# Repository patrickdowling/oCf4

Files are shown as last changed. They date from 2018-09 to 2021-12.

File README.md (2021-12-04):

# OC + F4
For grins I made an F405-based Teensy replacement for [o\_C](https://github.com/patrickdowling/O_C).

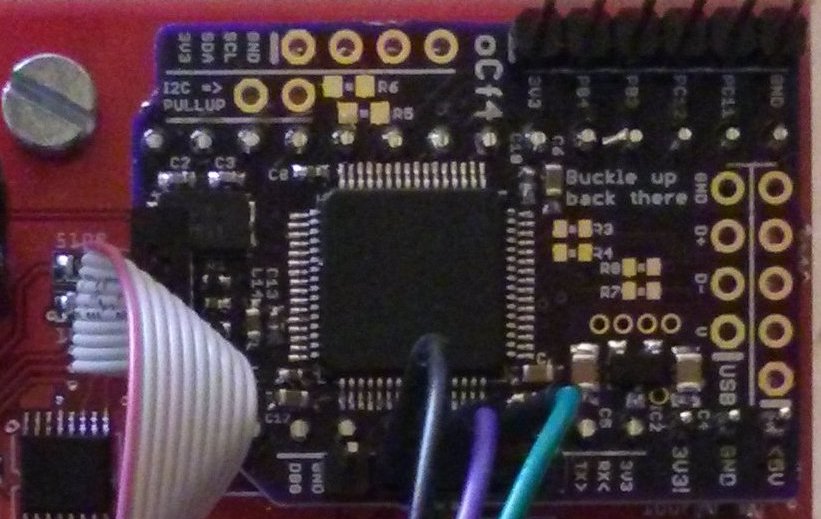
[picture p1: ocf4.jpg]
OCF4


It seemed like a good idea at the time and was an "excuse" to add F4 support to my F0 framework which then became
[stm32x](https://github.com/patrickdowling/stm32x).

The four-layer board is pretty tightly packed and tried to include everything and the kitchen sink (I2C, serial/MIDI, USB header...). There's even space for an SPI flash chip on the bottom... It should also be noted that I'm really just winging it when it comes to hardware design.

The single point of annoyance (the shared SPI between the DAC and screen) however remains although it is possible to run the thing at closer to 30KHz here (the Teensy 3.2 on `o_C` was effectively maxxing out at 16.6KHz with the 30MHz SPI).

Utlimately though, once the base drivers (ADC/TR/DAC/screen) were working it didn't actually have a purpose so there's very little actual functionality. Except a very early draft of what might be a "better" framework. So here it is anyway, warts
and all.

If someone does want to pursue this further, let me know.

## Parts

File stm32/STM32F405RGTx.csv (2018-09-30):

Position | Name | Type | Signal | Label
1 | VBAT | Power
2 | PC13-ANTI_TAMP | Output | GPIO_Output | RST_DAC
3 | PC14-OSC32_IN | Output | GPIO_Output | CS_DAC
4 | PC15-OSC32_OUT | I/O
5 | PH0-OSC_IN | I/O | RCC_OSC_IN
6 | PH1-OSC_OUT | I/O | RCC_OSC_OUT
7 | NRST | Reset
8 | PC0 | Output | GPIO_Output | FLASH_CS
9 | PC1 | I/O
10 | PC2 | I/O
11 | PC3 | I/O
12 | VSSA | Power
13 | VDDA | Power
14 | PA0-WKUP | Input | GPIO_Input | ENC_R2
15 | PA1 | Input | GPIO_Input | ENC_R1
16 | PA2 | Input | GPIO_Input | SW_R
17 | PA3 | Input | GPIO_Input | GND
18 | VSS | Power
19 | VDD | Power
20 | PA4 | Output | GPIO_Output | DBG
21 | PA5 | I/O | SPI1_SCK
22 | PA6 | Input | GPIO_Input | ENC_L2
23 | PA7 | I/O | ADC1_IN7 | CV2
24 | PC4 | I/O | ADC1_IN14 | CV4
25 | PC5 | I/O | ADC1_IN15 | CV3
26 | PB0 | I/O | ADC1_IN8 | CV1
27 | PB1 | Input | GPIO_Input | USB_PWR_FAULT
28 | PB2 | Input | GPIO_Input | ENC_L1
29 | PB10 | I/O | USART3_TX
30 | PB11 | I/O | USART3_RX
31 | VCAP_1 | Power
32 | VDD | Power
33 | PB12 | Input | GPIO_Input | SW_L
34 | PB13 | I/O | SPI2_SCK
35 | PB14 | I/O | SPI2_MISO
36 | PB15 | I/O | SPI2_MOSI
37 | PC6 | I/O | TIM3_CH1 | TR2
38 | PC7 | I/O | TIM3_CH2 | TR1
39 | PC8 | I/O | TIM3_CH3 | TR3
40 | PC9 | I/O | TIM3_CH4 | TR4
41 | PA8 | Output | GPIO_Output | USB_PWR_EN
42 | PA9 | Input | GPIO_Input | USB_OTG_FS_VBUS
43 | PA10 | I/O | USB_OTG_FS_ID
44 | PA11 | I/O | USB_OTG_FS_DM
45 | PA12 | I/O | USB_OTG_FS_DP
46 | PA13 | I/O | SYS_JTMS-SWDIO
47 | VCAP_2 | Power
48 | VDD | Power
49 | PA14 | I/O | SYS_JTCK-SWCLK
50 | PA15 | Input | GPIO_Input | SW_T
51 | PC10 | Input | GPIO_Input | SW_B
52 | PC11 | Output | GPIO_Output | PC11
53 | PC12 | Output | GPIO_Output | PC12
54 | PD2 | Output | GPIO_Output | DC
55 | PB3 | Output | GPIO_Output | PB3
56 | PB4 | Output | GPIO_Output | PB4
57 | PB5 | I/O | SPI1_MOSI
58 | PB6 | Output | GPIO_Output | RST
59 | PB7 | Output | GPIO_Output | CS_OLED
60 | BOOT0 | Boot
61 | PB8 | I/O | I2C1_SCL
62 | PB9 | I/O | I2C1_SDA
63 | VSS | Power
64 | VDD | Power

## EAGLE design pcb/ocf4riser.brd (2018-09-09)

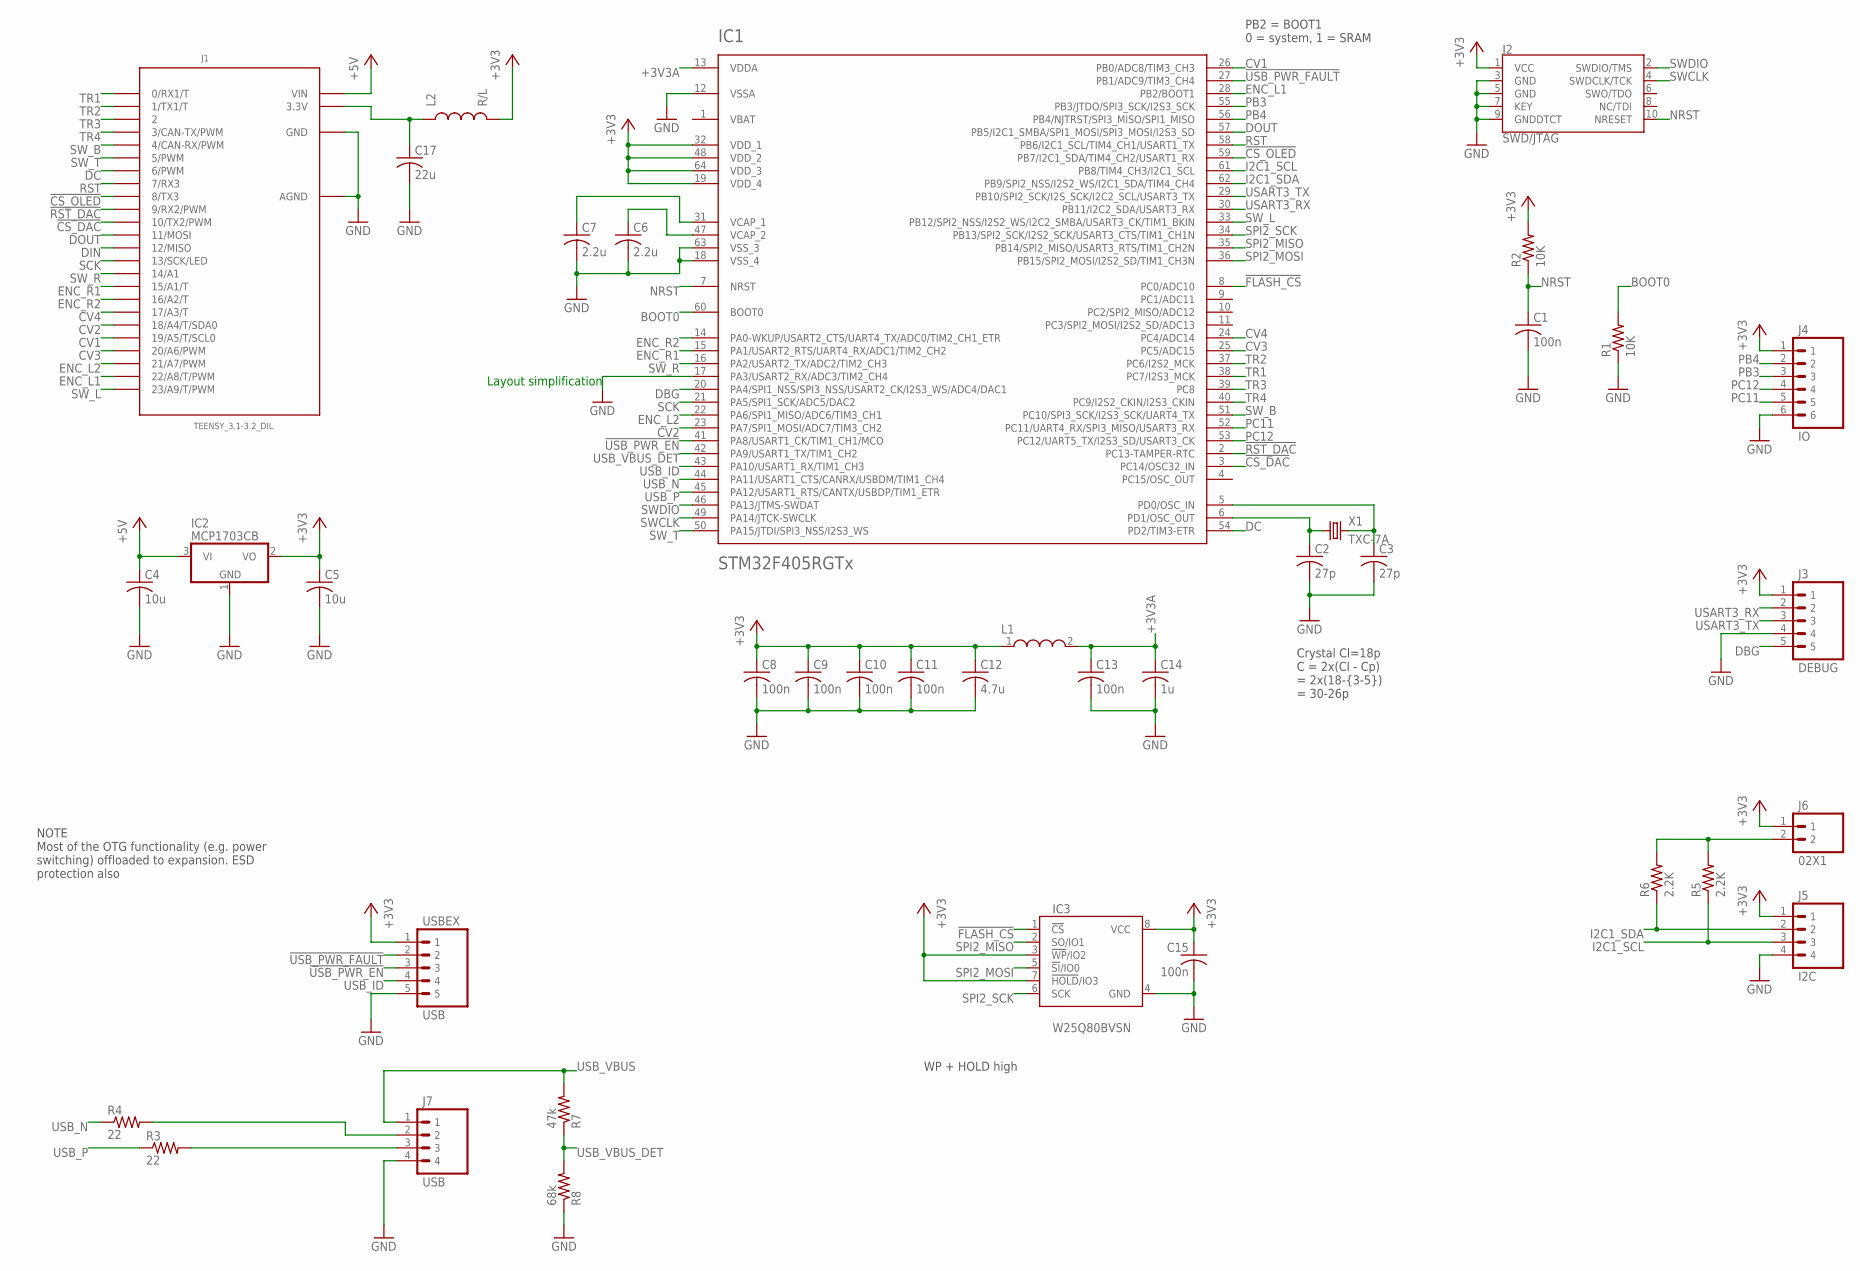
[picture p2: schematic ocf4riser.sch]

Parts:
C1, C8, C9, C10, C11, C13, C15: 100n; C0402
C2, C3: 27p; C0402
C4, C5: 10u; C0805
C6, C7: 2.2u; C0603
C12: 4.7u; C0603
C14: 1u; C0603
C17: 22u; C0805
IC1: STM32F405RGTx; TQFP-10X10-64
IC2: MCP1703CB; SOT23
IC3: W25Q80BVSN; SOIC-8
J1: TEENSY_3.1-3.2_DIL; TEENSY_3.0-3.2&LC_DIL
J2: SWD/JTAG; 2X5-1.27
J3: DEBUG; 05X1-THIN
J4: IO; 06X1-THIN
J5: I2C; 04X1-THIN
J6: 02X1; 02X1-THIN
J7: USB; 04X1-THIN
L1: WE-CBF_0603(WB/HS); WE-CBF_0603(W=2.2)
L2: R/L; 0805
R1, R2: 10K; R0402
R3, R4: 22; R0402
R5, R6: 2.2K; R0603
R7: 47k; R0402
R8: 68k; R0402
USBEX: USB; 05X1-THIN
X1: TXC-7A; CRYSTAL-TXC-7A

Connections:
!CS_DAC: IC1.3 (PC14/OSC32_IN), J1.10 (10/TX2/PWM)
!CS_OLED: IC1.59 (PB7/I2C1_SDA/TIM4_CH2/USART1_RX), J1.8 (8/TX3)
!FLASH_CS: IC1.8 (PC0/ADC10), IC3.1 (!CS!)
!RST_DAC: IC1.2 (PC13-TAMPER-RTC), J1.9 (9/RX2/PWM)
!USB_PWR_EN: IC1.41 (PA8/USART1_CK/TIM1_CH1/MCO), USBEX.3
!USB_PWR_FAULT: IC1.27 (PB1/ADC9/TIM3_CH4), USBEX.2
+3V3: C5.1, C8.1, C9.1, C10.1, C11.1, C12.1, C15.1, IC1.19 (VDD_4), IC1.32 (VDD_1), IC1.48 (VDD_2), IC1.64 (VDD_3), IC2.2 (VO), IC3.3 (!WP!/IO2), IC3.7 (!HOLD!/IO3), IC3.8 (VCC), J2.1 (VCC), J3.1, J4.1, J5.1, J6.1, L1.1, L2.2, R2.2, USBEX.1
+3V3A: C13.1, C14.1, IC1.13 (VDDA), L1.2
+5V: C4.1, IC2.3 (VI), J1.VIN
BOOT0: IC1.60 (BOOT0), R1.2
CV1: IC1.26 (PB0/ADC8/TIM3_CH3), J1.19/A5 (19/A5/T/SCL0)
CV2: IC1.23 (PA7/SPI1_MOSI/ADC7/TIM3_CH2), J1.18/A4 (18/A4/T/SDA0)
CV3: IC1.25 (PC5/ADC15), J1.20/A6 (20/A6/PWM)
CV4: IC1.24 (PC4/ADC14), J1.17/A3 (17/A3/T)
DBG: IC1.20 (PA4/SPI1_NSS/SPI3_NSS/USART2_CK/I2S3_WS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), J3.5
DC: IC1.54 (PD2/TIM3-ETR), J1.6 (6/PWM)
DIN: J1.12 (12/MISO)
DOUT: IC1.57 (PB5/I2C1_SMBA/SPI1_MOSI/SPI3_MOSI/I2S3_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), J1.11 (11/MOSI)
ENC_L1: IC1.28 (PB2/BOOT1), J1.22/A8 (22/A8/T/PWM)
ENC_L2: IC1.22 (PA6/SPI1_MISO/ADC6/TIM3_CH1), J1.21/A7 (21/A7/PWM)
ENC_R1: IC1.15 (PA1/USART2_RTS/UART4_RX/ADC1/TIM2_CH2), J1.15/A1 (15/A1/T)
ENC_R2: IC1.14 (PA0-WKUP/USART2_CTS/UART4_TX/ADC0/TIM2_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), J1.16/A2 (16/A2/T)
GND: C1.2, C2.2, C3.2, C4.2, C5.2, C6.2, C7.2, C8.2, C9.2, C10.2, C11.2, C12.2, C13.2, C14.2, C15.2, C17.2, IC1.12 (VSSA), IC1.17 (PA3/USART2_RX/ADC3/TIM2_CH4), IC1.18 (VSS_4), IC1.63 (VSS_3), IC2.1 (GND), IC3.4 (GND), J1.AGND, J1.GND, J2.3 (GND), J2.5 (GND), J2.7 (KEY), J2.9 (GNDDTCT), J3.4, J4.6, J5.4, J7.4, R1.1, R8.1, USBEX.5
I2C1_SCL: IC1.61 (PB8/TIM4_CH3/I2C1_SCL), J5.3, R5.1
I2C1_SDA: IC1.62 (PB9/SPI2_NSS/I2S2_WS/I2C1_SDA/TIM4_CH4), J5.2, R6.1
I2C_PU: J6.2, R5.2, R6.2
unnamed: C17.1, J1.3.3V, L2.1
unnamed: C3.1, IC1.5 (PD0/OSC_IN), X1.P$2 (2)
unnamed: C2.1, IC1.6 (PD1/OSC_OUT), X1.P$1 (1)
NRST: C1.1, IC1.7 (NRST), J2.10 (NRESET), R2.1
PB3: IC1.55 (PB3/JTDO/SPI3_SCK/I2S3_SCK), J4.3
PB4: IC1.56 (PB4/NJTRST/SPI3_MISO/SPI1_MISO), J4.2
PC11: IC1.52 (PC11/UART4_RX/SPI3_MISO/USART3_RX), J4.5
PC12: IC1.53 (PC12/UART5_TX/I2S3_SD/USART3_CK), J4.4
RST: IC1.58 (PB6/I2C1_SCL/TIM4_CH1/USART1_TX), J1.7 (7/RX3)
SCK: IC1.21 (PA5/SPI1_SCK/ADC5/DAC2), J1.13 (13/SCK/LED)
SPI2_MISO: IC1.35 (PB14/SPI2_MISO/USART3_RTS/TIM1_CH2N), IC3.2 (SO/IO1)
SPI2_MOSI: IC1.36 (PB15/SPI2_MOSI/I2S2_SD/TIM1_CH3N), IC3.5 (!SI!/IO0)
SPI2_SCK: IC1.34 (PB13/SPI2_SCK/I2S2_SCK/USART3_CTS/TIM1_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), IC3.6 (SCK)
SWCLK: IC1.49 (PA14/JTCK-SWCLK), J2.4 (SWDCLK/TCK)
SWDIO: IC1.46 (PA13/JTMS-SWDAT), J2.2 (SWDIO/TMS)
SW_B: IC1.51 (PC10/SPI3_SCK/I2S3_SCK/UART4_TX), J1.4 (4/CAN-RX/PWM)
SW_L: IC1.33 (PB12/SPI2_NSS/I2S2_WS/I2C2_SMBA/USART3_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), J1.23/A9 (23/A9/T/PWM)
SW_R: IC1.16 (PA2/USART2_TX/ADC2/TIM2_CH3), J1.14/A0 (14/A1)
SW_T: IC1.50 (PA15/JTDI/SPI3_NSS/I2S3_WS), J1.5 (5/PWM)
TR1: IC1.38 (PC7/I2S3_MCK), J1.0 (0/RX1/T)
TR2: IC1.37 (PC6/I2S2_MCK), J1.1 (1/TX1/T)
TR3: IC1.39 (PC8), J1.2
TR4: IC1.40 (PC9/I2S2_CKIN/I2S3_CKIN), J1.3 (3/CAN-TX/PWM)
USART3_RX: IC1.30 (PB11/I2C2_SDA/USART3_RX), J3.2
USART3_TX: IC1.29 (PB10/SPI2_SCK/I2S_SCK/I2C2_SCL/USART3_TX), J3.3
USB_ID: IC1.43 (PA10/USART1_RX/TIM1_CH3), USBEX.4
USB_I_N: J7.2, R4.2
USB_I_P: J7.3, R3.2
USB_N: IC1.44 (PA11/USART1_CTS/CANRX/USBDM/TIM1_CH4), R4.1
USB_P: IC1.45 (PA12/USART1_RTS/CANTX/USBDP/TIM1_ETR), R3.1
USB_VBUS: J7.1, R7.2
USB_VBUS_DET: IC1.42 (PA9/USART1_TX/TIM1_CH2), R7.1, R8.2
VBAT: IC1.1 (VBAT)
VCAP_1: C7.1, IC1.31 (VCAP_1)
VCAP_2: C6.1, IC1.47 (VCAP_2)

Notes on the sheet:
Layout simplification
PB2 = BOOT1 0 = system, 1 = SRAM
WP + HOLD high
NOTE Most of the OTG functionality (e.g. power switching) offloaded to expansion. ESD protection also
Crystal Cl=18p C = 2x(Cl - Cp) = 2x(18-{3-5}) = 30-26p

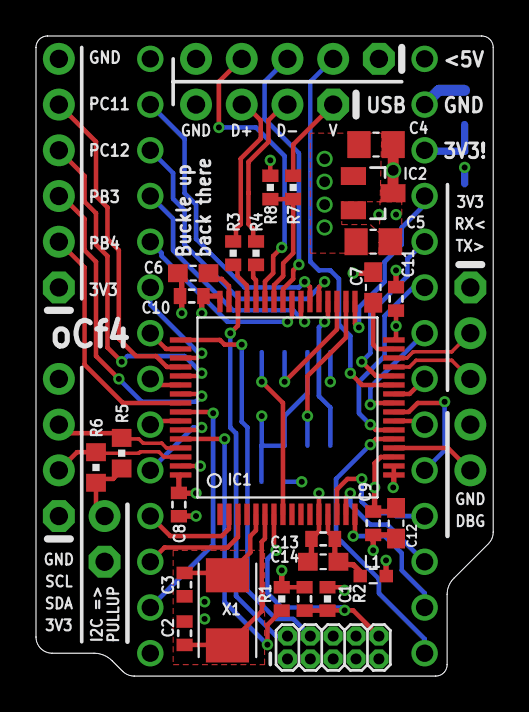
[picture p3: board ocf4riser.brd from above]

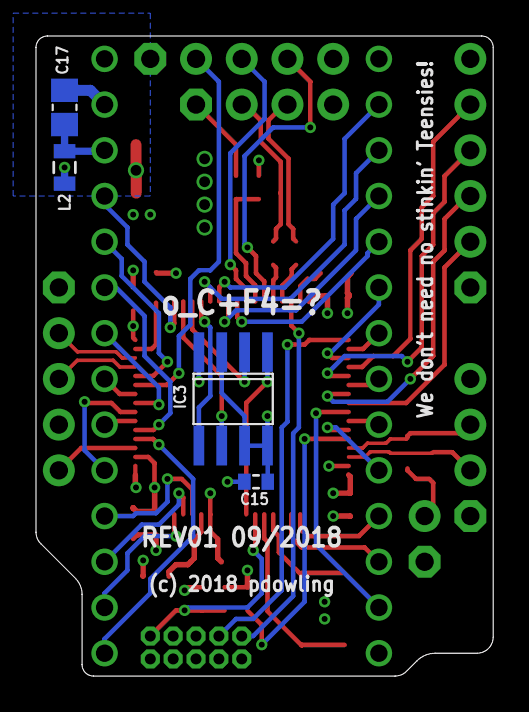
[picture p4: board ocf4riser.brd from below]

Board: 4 copper layers, 25.4 x 35.6 mm, 38 parts (4 on the bottom side), 59 nets.

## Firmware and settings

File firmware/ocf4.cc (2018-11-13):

// Copyright 2018 Patrick Dowling
//
// Author: Patrick Dowling (pld@gurkenkiste.com)
//
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
// See http://creativecommons.org/licenses/MIT/ for more information.
//
// Main runtime for ocf4

#include "ocf4.h"
#include "calibration_data.h"
#include "display.h"
#include "patch.h"
#include "drivers/adc.h"
#include "drivers/digital_inputs.h"
#include "drivers/gpio.h"
#include "drivers/core_timer.h"
#include "drivers/dac.h"
#include "drivers/serial_port.h"
#include "stm32x/stm32x_core.h"
#include "stm32x/stm32x_debug.h"
#include "ui/ui.h"
#include "builtin/calibration_patch.h"
#include "builtin/debug_menu.h"
#include "builtin/io_frame_debug.h"

namespace ocf4 {

  DebugStats DEBUG_STATS;
  CalibrationData calibration_data;

  GPIO gpio;
  Adc adc;
  CoreTimer core_timer;
  DigitalInputs digital_inputs;
  Spi shared_spi;
  Display display{shared_spi};
  Dac dac{shared_spi};
  SerialPort serial_port;

  Ui ui;
  DebugMenu debug_menu;

} // namespace ocf4
STM32X_CORE_DEFINE()

using namespace ocf4;
using namespace stm32x;

static PatchMemoryPool patch_memory_pool;
static Patch current_patch{patch_memory_pool};
static IOFrame io_frame;
static IOFrameDebug io_frame_debug{io_frame};

extern "C" void CORE_TIMER_HANDLER() {
  if (!core_timer.Ticked())
    return;

  DEBUG_PROFILE_SCOPE(DEBUG_STATS.CORE.core_timer_cycles);
  display.Flush();
  dac.Update(io_frame.out);
  adc.Read(io_frame.adc_in);
  adc.StartConversion();
  digital_inputs.Read(io_frame.digital_inputs);
  display.Update();
  ++io_frame.tick;

  // Stuff happens here
  if (current_patch.enabled())
    current_patch.Process(io_frame);
}

extern "C" void SysTick_Handler() {
  STM32X_CORE_TICK();
  ui.Poll();
  ui.Tick();
}

class TestProc : public Processor {
public:
  static constexpr uint32_t type_id = FOURCC<'T','E','S','T'>::value;
  virtual void Init(PatchMemoryPool &) final { }
  virtual void Process(IOFrame &frame) final {
    frame.out[0] = a++;
    frame.out[1] = b++;
  }

private:
  uint16_t a = 0, b = 0xffff/4, c = 0xffff/2, d = 0xffff*3 / 4;
};

class TestProcGate : public Processor {
public:
  static constexpr uint32_t type_id = FOURCC<'G','A','T','E'>::value;

  TestProcGate(uint32_t pw) {
    pw_.set(pw);
  }

  virtual void Init(PatchMemoryPool &) final { }
  virtual void Process(IOFrame &frame) final {
    if (ticks_ > pw_.value()) {
      frame.out[2] = 65535;
      frame.out[3] = 0;
    } else {
      frame.out[2] = 0;
      frame.out[3] = 65535;
    }
    ++ticks_;
    if (ticks_ > kCoreUpdate)
      ticks_ = 0;
  }

  ParameterList parameter_list() const {
    return ParameterList(parameters_.size(), parameters_.data());
  }

private:
  uint32_t ticks_ = 0;
  EditableParameter<uint32_t> pw_ = {"PW", kCoreUpdate / 2};

  const std::array<EditableParameterBase*, 2> parameters_ = {
    &pw_,
    nullptr
  };
};

int main()
{
  STM32X_DEBUG_INIT();
  STM32X_CORE_INIT(F_CPU / kSysTickUpdate);

  // FIXME Init order smells suspicious

  debug_menu.Init();
  debug_menu.AddPage("IO", &io_frame_debug);
  debug_menu.AddPage("PATCH", &current_patch);
  ui.PushMenu(&debug_menu);

  display.AdjustOffset(calibration_data.display_offset);
  display.Init();
/*
  CalibrationPatch::Load(current_patch);
  ui.PushMenu(current_patch.root_menu());
*/

  current_patch.Reset();
  current_patch.AddProcessor<TestProc>();
  current_patch.AddProcessor<TestProcGate>(kCoreUpdate / 2);
  current_patch.enable(true);

  serial_port.Init(9600);

  core_timer.Start(F_CPU / kCoreUpdate - 1);
  while (true) {
    ui.DispatchEvents();
    current_patch.IdleLoop();
    ui.Draw();

    while (serial_port.readable()) {
      switch (serial_port.Read()) {
        case '?': serial_port.Write('!');
        default: break;
      }
    }
 }
}

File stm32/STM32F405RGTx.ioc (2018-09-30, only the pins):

Mcu.UserName=STM32F405RGTx
PA0-WKUP.GPIO_Label=ENC_R2
PA0-WKUP.Signal=GPIO_Input
PA1.GPIO_Label=ENC_R1
PA1.Signal=GPIO_Input
PA10.Signal=USB_OTG_FS_ID
PA11.Signal=USB_OTG_FS_DM
PA12.Signal=USB_OTG_FS_DP
PA13.Signal=SYS_JTMS-SWDIO
PA14.Signal=SYS_JTCK-SWCLK
PA15.GPIO_Label=SW_T
PA15.Signal=GPIO_Input
PA2.GPIO_Label=SW_R
PA2.Signal=GPIO_Input
PA3.GPIO_Label=GND
PA3.Signal=GPIO_Input
PA4.GPIO_Label=DBG
PA4.Signal=GPIO_Output
PA5.Signal=SPI1_SCK
PA6.GPIO_Label=ENC_L2
PA6.Signal=GPIO_Input
PA7.GPIO_Label=CV2
PA7.Signal=ADCx_IN7
PA8.GPIO_Label=USB_PWR_EN
PA8.Signal=GPIO_Output
PA9.GPIO_Label=USB_OTG_FS_VBUS
PA9.Signal=GPIO_Input
PB0.GPIO_Label=CV1
PB0.Signal=ADCx_IN8
PB1.GPIO_Label=USB_PWR_FAULT
PB1.Signal=GPIO_Input
PB10.Signal=USART3_TX
PB11.Signal=USART3_RX
PB12.GPIO_Label=SW_L
PB12.Signal=GPIO_Input
PB13.Signal=SPI2_SCK
PB14.Signal=SPI2_MISO
PB15.Signal=SPI2_MOSI
PB2.GPIO_Label=ENC_L1
PB2.Signal=GPIO_Input
PB3.GPIO_Label=PB3
PB3.Signal=GPIO_Output
PB4.GPIO_Label=PB4
PB4.Signal=GPIO_Output
PB5.Signal=SPI1_MOSI
PB6.GPIO_Label=RST
PB6.Signal=GPIO_Output
PB7.GPIO_Label=CS_OLED
PB7.Signal=GPIO_Output
PB8.Signal=I2C1_SCL
PB9.Signal=I2C1_SDA
PC0.GPIO_Label=FLASH_CS
PC0.Signal=GPIO_Output
PC10.GPIO_Label=SW_B
PC10.Signal=GPIO_Input
PC11.GPIO_Label=PC11
PC11.Signal=GPIO_Output
PC12.GPIO_Label=PC12
PC12.Signal=GPIO_Output
PC13-ANTI_TAMP.GPIO_Label=RST_DAC
PC13-ANTI_TAMP.Signal=GPIO_Output
PC14-OSC32_IN.GPIO_Label=CS_DAC
PC14-OSC32_IN.Signal=GPIO_Output
PC4.GPIO_Label=CV4
PC4.Signal=ADCx_IN14
PC5.GPIO_Label=CV3
PC5.Signal=ADCx_IN15
PC6.GPIO_Label=TR2
PC6.Signal=S_TIM3_CH1
PC7.GPIO_Label=TR1
PC7.Signal=S_TIM3_CH2
PC8.GPIO_Label=TR3
PC8.Signal=S_TIM3_CH3
PC9.GPIO_Label=TR4
PC9.Signal=S_TIM3_CH4
PD2.GPIO_Label=DC
PD2.Signal=GPIO_Output
PH0-OSC_IN.Signal=RCC_OSC_IN
PH1-OSC_OUT.Signal=RCC_OSC_OUT

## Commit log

2018-09-02 Pin headers, values & names
    [ocf4riser.brd, ocf4riser.sch]
2018-09-08 USB as header instead of receptacle
    [ocf4riser.brd, ocf4riser.sch]
2018-09-30 Skeleton firmware using stm32x, display driver somewhat functional
    [STM32F405RGTx.csv]
2018-09-30 Initial support for DAC, core update timer
2018-09-30 ADC driver skeleton
2018-10-09 Skeleton patch infrastructure, ADC experiments with oversampling
2018-10-10 Fix DAC CS pin, tweak ADC, misc
    [adc.cc, dac.cc, ocf4.cc]
2018-10-14 Steps towards patch/processor/ui framework, misc
2018-10-21 Use concrete type for pooled instantiations, update stm32x

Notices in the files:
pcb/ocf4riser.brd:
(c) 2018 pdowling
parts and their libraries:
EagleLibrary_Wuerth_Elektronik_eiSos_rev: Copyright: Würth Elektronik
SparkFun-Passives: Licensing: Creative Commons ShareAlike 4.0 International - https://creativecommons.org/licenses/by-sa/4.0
